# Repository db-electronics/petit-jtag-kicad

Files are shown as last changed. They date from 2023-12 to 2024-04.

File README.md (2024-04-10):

# Petit JTAG
Petit JTAG is a USB Blaster adapter which reduces the 2x5 100mil connector to a 1x6 2mm connector when space is constrained on the target PCB. It also has a type B USB input to provide power to the target board from either VBUS 5V or 3.3V from an onboard voltage regulator. This is selectable via pin header.

# Support Open Source
If you're going to use my free projects please consider sponsoring my work. Thanks!

- [Github Sponsor](https://github.com/sponsors/db-electronics)
- [Pateron](https://patreon.com/dbelectronics)

# Changelog
- [v1.1](https://github.com/db-electronics/petit-jtag-kicad/releases/tag/v1.1)
  - change 2x3 50mil to a 1x6 2mm staggered footprint for more consistent connection to target board
- [v1.0](https://github.com/db-electronics/petit-jtag-kicad/releases/tag/v1.0)
  - initial release

# Copyright and Disclaimer
Copyright: René Richard

This documentation describes Open Hardware and is licensed under the
CERN OHL v. 1.2.

You may redistribute and modify this documentation under the terms of the
CERN OHL v.1.2. (http://ohwr.org/cernohl). This documentation is distributed
WITHOUT ANY EXPRESS OR IMPLIED WARRANTY, INCLUDING OF
MERCHANTABILITY, SATISFACTORY QUALITY AND FITNESS FOR A
PARTICULAR PURPOSE. Please see the CERN OHL v.1.2 for applicable
conditions

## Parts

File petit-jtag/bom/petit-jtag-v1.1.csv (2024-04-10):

Item | Qty | Reference(s) | Value | LibPart | Footprint | Description | Digikey | Supplier | Supplier Number
1 | 2 | C101, C102 | 10uF | C_0805 | 0805 | CAP CER 10UF 16V X5R 0805 | #ND | www.digikey.ca | 1276-1096-1-ND
2 | 1 | CON101 | 2PH1-06-UA | JTAG-1X6-2MM-HDR | HDR1X6_2MM | CONN HEADER VERT 6POS 2MM |  | www.digikey.ca | 2057-2PH1-06-UA-ND
3 | 1 | CON102 | USB-B1HSB6 | USB-B1HSB6 | USB-B1HSxx | CONN USB TYPE B R/A BLACK |  | www.digikey.ca | ED2983-ND
4 | 1 | CON103 | 302-S101 | JTAG-2X5-HDR-SHROUD_1 | HDR2X5-JTAG_SHROUD | USB BLASTER JTAG 2X5 HEADER |  | www.digikey.ca | ED1543-ND
5 | 1 | CON104 | 61300311121 | HDR1X3_1 | HDR1X3 | CONN HEADER VERT 3POS 2.54MM |  | www.digikey.ca | 732-5316-ND
6 | 1 | CON105 | 61300211121 | HDR1X2_1 | HDR1X2 | CONN HEADER VERT 2POS 2.54MM |  | www.digikey.ca | 732-5315-ND
7 | 1 | CON106 | 61301021121 | HDR2X5_1 | HDR2X5-JTAG | CONN HEADER VERT 10POS 2.54MM |  | www.digikey.ca | 732-2672-ND
8 | 1 | U101 | AZ1117CH-3.3TRG1 | AZ1117CH-3.3TRG1_1 | SOT-223 | IC REG LINEAR 3.3V 800MA SOT223 |  | www.digikey.ca | AZ1117CH-3.3TRG1DICT-ND

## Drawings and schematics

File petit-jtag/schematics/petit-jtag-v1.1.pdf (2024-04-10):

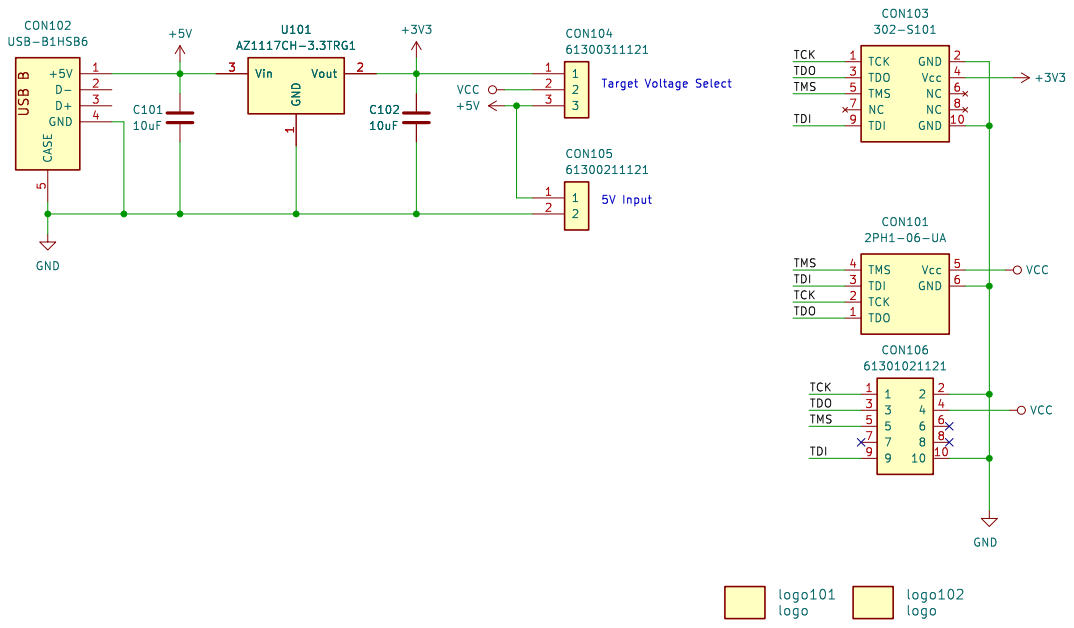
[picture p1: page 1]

Target Voltage Select 5V Input U101 AZ1117CH-3.3TRG1 GND

https://github.com/db-electronics/petit-jtag-kicad

Id: 1/1 Title: Petit JTAG

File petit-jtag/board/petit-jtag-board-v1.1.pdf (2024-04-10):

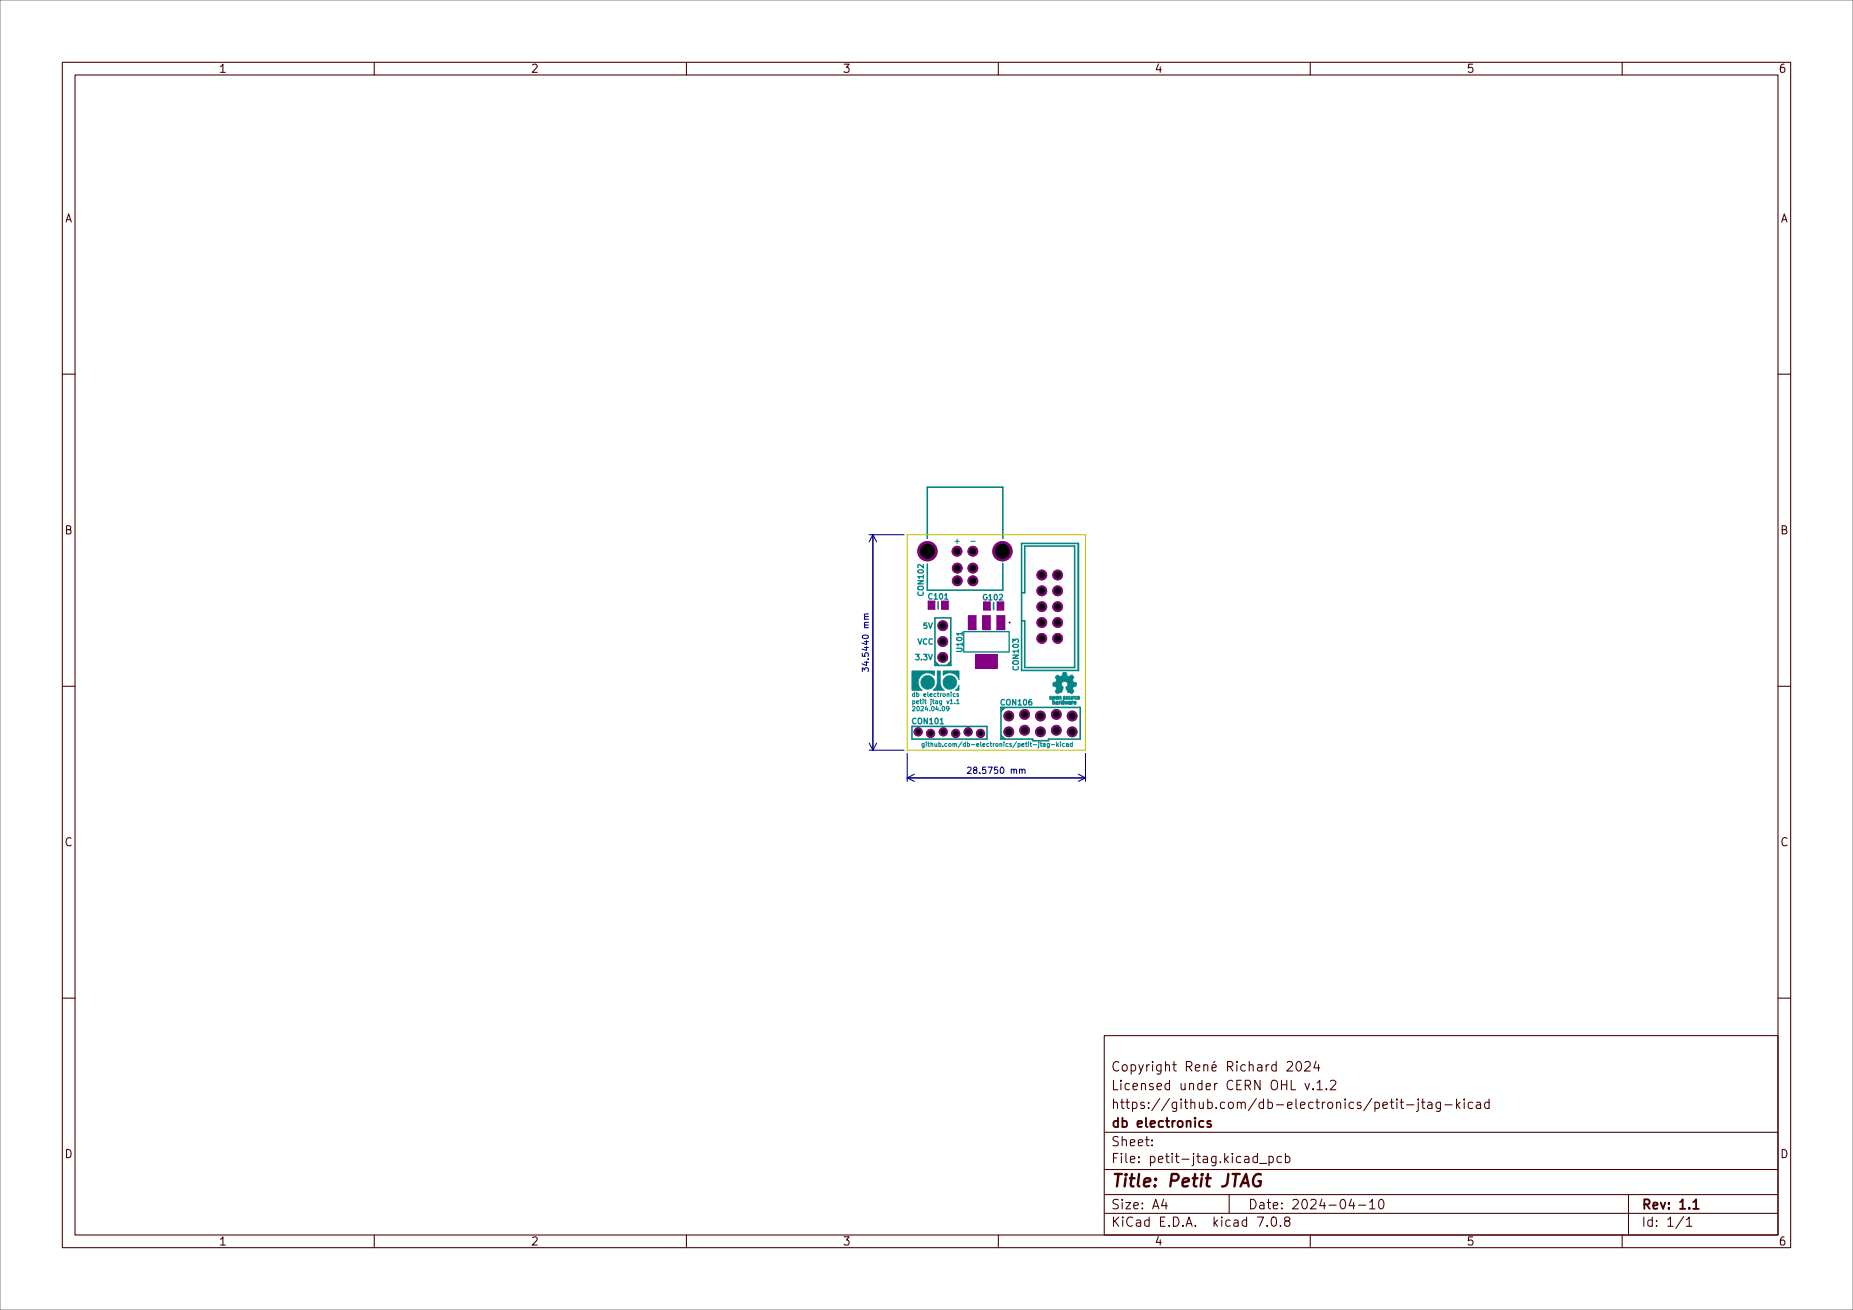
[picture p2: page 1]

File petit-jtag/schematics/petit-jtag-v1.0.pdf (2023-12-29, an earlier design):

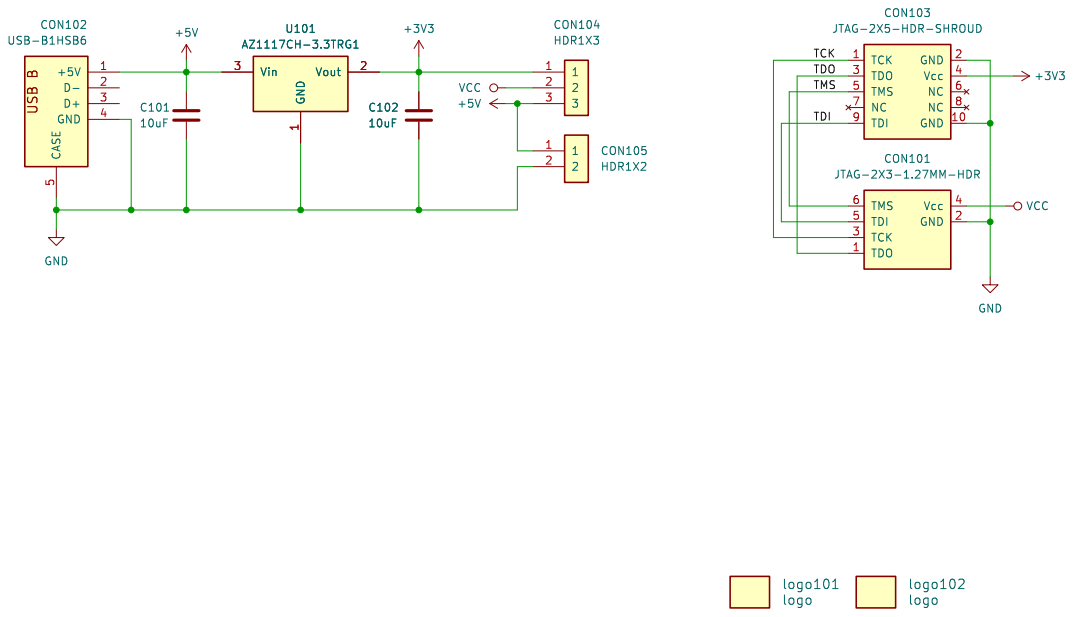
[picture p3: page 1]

https://github.com/db-electronics/petit-jtag-kicad

Id: 1/1 Title: Petit JTAG

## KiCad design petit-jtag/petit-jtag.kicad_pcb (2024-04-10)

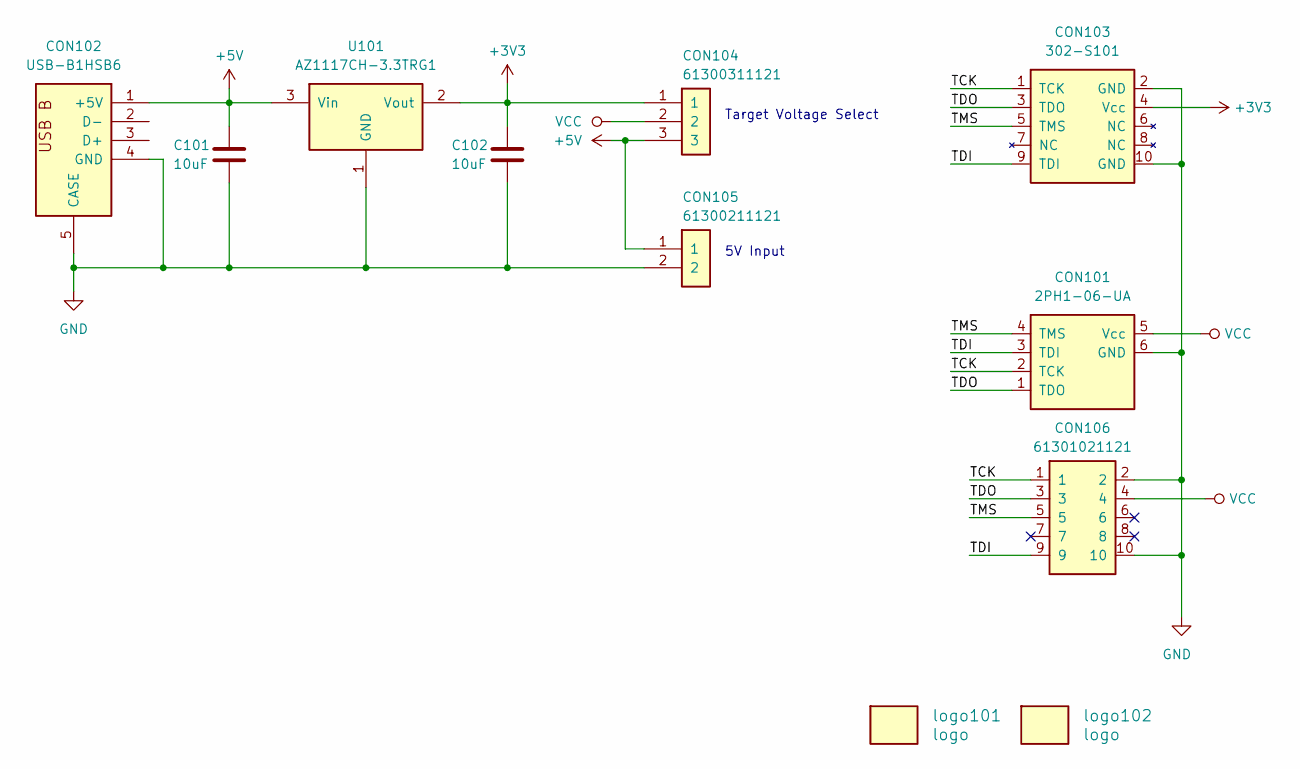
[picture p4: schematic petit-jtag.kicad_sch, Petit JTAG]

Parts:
C101, C102: 10uF; 0805
CON101: 2PH1-06-UA; HDR1X6_2MM
CON102: USB-B1HSB6; USB-B1HSxx
CON103: 302-S101; HDR2X5-JTAG_SHROUD
CON104: 61300311121; HDR1X3
CON105: 61300211121; HDR1X2
CON106: 61301021121; HDR2X5-JTAG
U101: AZ1117CH-3.3TRG1; SOT-223
logo101: logo; db-logo_7.5mm
logo102: logo; oshw-logo_5mm

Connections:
+3V3: C102.1, CON103.4 (Vcc), CON104.1, U101.2 (Vout)
+5V: C101.1, CON102.1 (+5V), CON104.3, CON105.1, U101.3 (Vin)
/TCK: CON101.2 (TCK), CON103.1 (TCK), CON106.1
/TDI: CON101.3 (TDI), CON103.9 (TDI), CON106.9
/TDO: CON101.1 (TDO), CON103.3 (TDO), CON106.3
/TMS: CON101.4 (TMS), CON103.5 (TMS), CON106.5
GND: C101.2, C102.2, CON101.6 (GND), CON102.4 (GND), CON102.5 (CASE), CON103.2 (GND), CON103.10 (GND), CON105.2, CON106.2, CON106.10, U101.1 (GND)
VCC: CON101.5 (Vcc), CON104.2, CON106.4

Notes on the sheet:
Target Voltage Select
5V Input

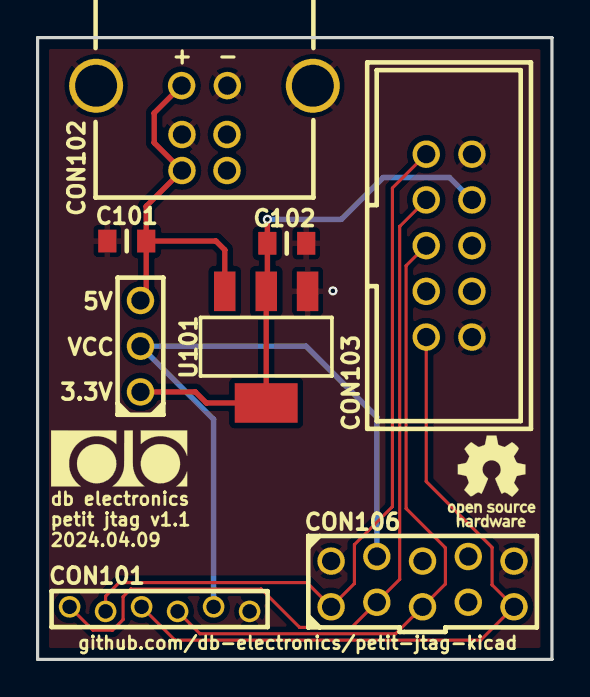
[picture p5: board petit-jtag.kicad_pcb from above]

Board: 2 copper layers, 28.6 x 34.5 mm, 11 parts (0 on the bottom side), 8 nets.

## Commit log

2023-12-28 initial file commiut
    [petit-jtag.kicad_pcb, petit-jtag.kicad_sch]
2023-12-29 mostly done v1.0
    [petit-jtag.kicad_pcb, petit-jtag.kicad_sch]
2023-12-29 version 1.0 ready
    [petit-jtag.kicad_pcb, petit-jtag.kicad_sch]
2023-12-29 add output files for v1.0
    [petit-jtag-B_Cu.gbl, petit-jtag-B_Mask.gbs, petit-jtag-B_Silkscreen.gbo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]
2023-12-29 added bom file
    [petit-jtag-v1.0.csv]
2024-04-05 updated with new staggered pin headers instead of 2x3
    [petit-jtag.kicad_pcb, petit-jtag.kicad_sch]
2024-04-08 petit-swd board
    [petit-swd.kicad_pcb, petit-swd.kicad_sch]
2024-04-10 swd v1.0 sch complete, jtag v1.1 files
    [petit-jtag-B_Cu.gbl, petit-jtag-B_Mask.gbs, petit-jtag-B_Silkscreen.gbo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]
2024-04-10 separate petit-swd into its own repo
    [petit-jtag-v1.1.csv, petit-jtag.kicad_pcb, petit-jtag.kicad_sch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]

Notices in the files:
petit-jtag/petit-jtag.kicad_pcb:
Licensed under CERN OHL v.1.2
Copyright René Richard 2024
